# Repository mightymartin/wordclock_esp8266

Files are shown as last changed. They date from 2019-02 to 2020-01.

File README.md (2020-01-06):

# Wordclock based on an ESP8266 / WS2812
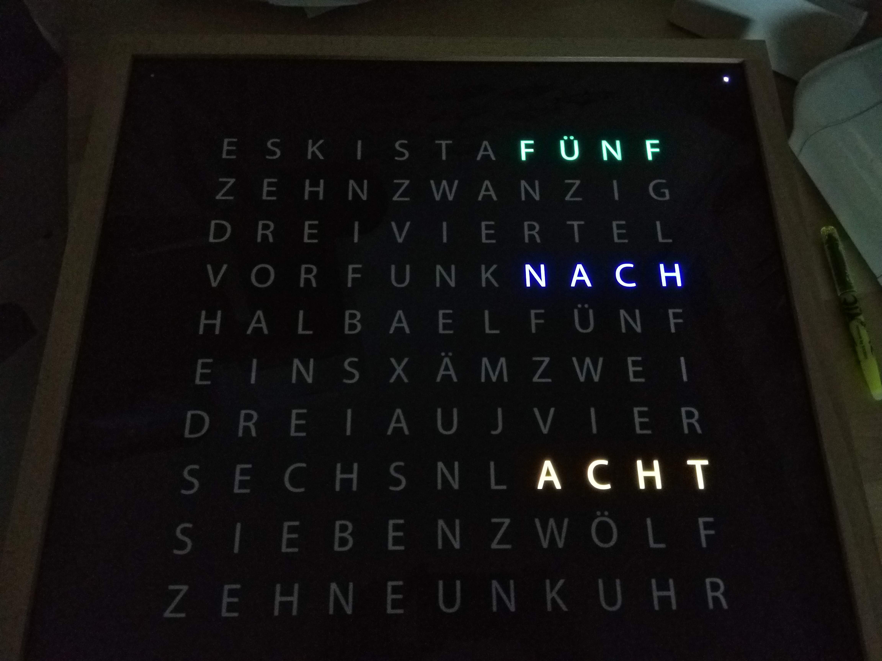
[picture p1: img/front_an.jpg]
front_an


## Hardware:
- LDR with voltagedevider on A0 
- WS2812 via levelshifter on RXD0 

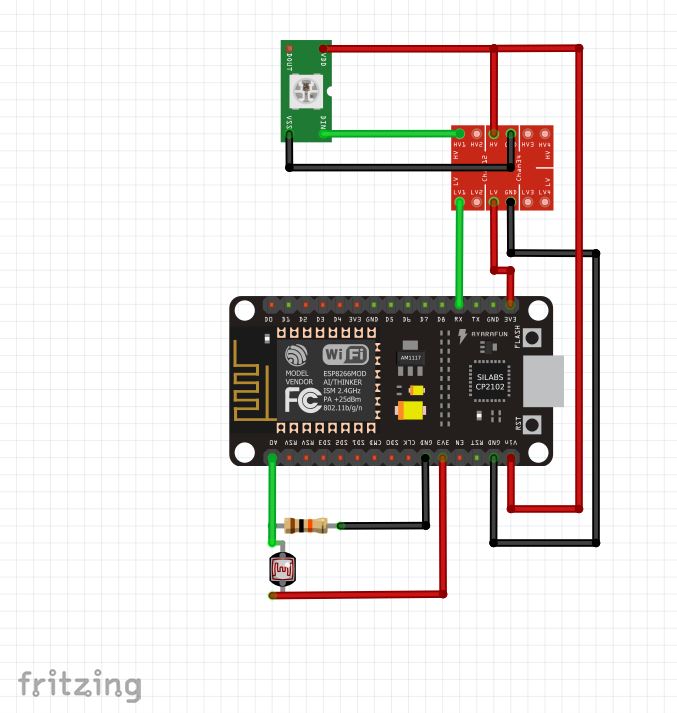
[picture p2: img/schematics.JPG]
wiring1


## Supported Layouts:
#Ikeahacker caschoff.de (page gone):
```
E S _ I S T _ F Ü N F
Z E H N Z W A N Z I G
D R E I V I E R T E L
N A C H F U N K V O R  
H A L B _ E L F Ü N F
E I N S _ _ _ Z W E I
D R E I _ _ _ V I E R
S E C H S _ _ A C H T
S I E B E N Z W Ö L F
Z E H N N E U N U H R
```

#ulrichradig.de (project gone):
```
E S _ I S T _ F Ü N F
Z E H N Z W A N Z I G
D R E I V I E R T E L
_ _ N A C H V O R _ _  
H A L B _ Z W Ö L F _
Z W E I N S I E B E N
_ D R E I _ _ F Ü N F
E L F N E U N V I E R
_ A C H T Z E H N _ _
_ S E C H S _ U H R _
```

#mikrocontroller.net:
```
E S _ I S T _ F Ü N F
Z E H N Z W A N Z I G
D R E I V I E R T E L
_ _ N A C H V O R _ _  
H A L B _ Z W Ö L F _
Z W E I N S I E B E N
_ D R E I _ _ F Ü N F
E L F N E U N V I E R
_ A C H T Z E H N _ _
_ S E C H S _ _ U H R
```

## Features:
- defineable hardware layout (leds.h)
- word fading
- display hour and minutes
- display seconds
- display temperature
- display marquee text
- display startscreen
- scheduled Auto ON / OFF Times
- 8 different color modes with HUE rotate
- wifimanger
- Webserver http://deviceip:80 ( inspired by Tasmota and tzapu/wifimanager )
- OTA
- mdns
- Websocket Webconsole
- NTP time client
- MQTT Sub: ON/OFF && BRIGHTNESS && COLORMODE && DISPLAYMODE (Non persistent)
- MQTT Pub: current config as JSON to broker
- LDR driven brightness

## Images
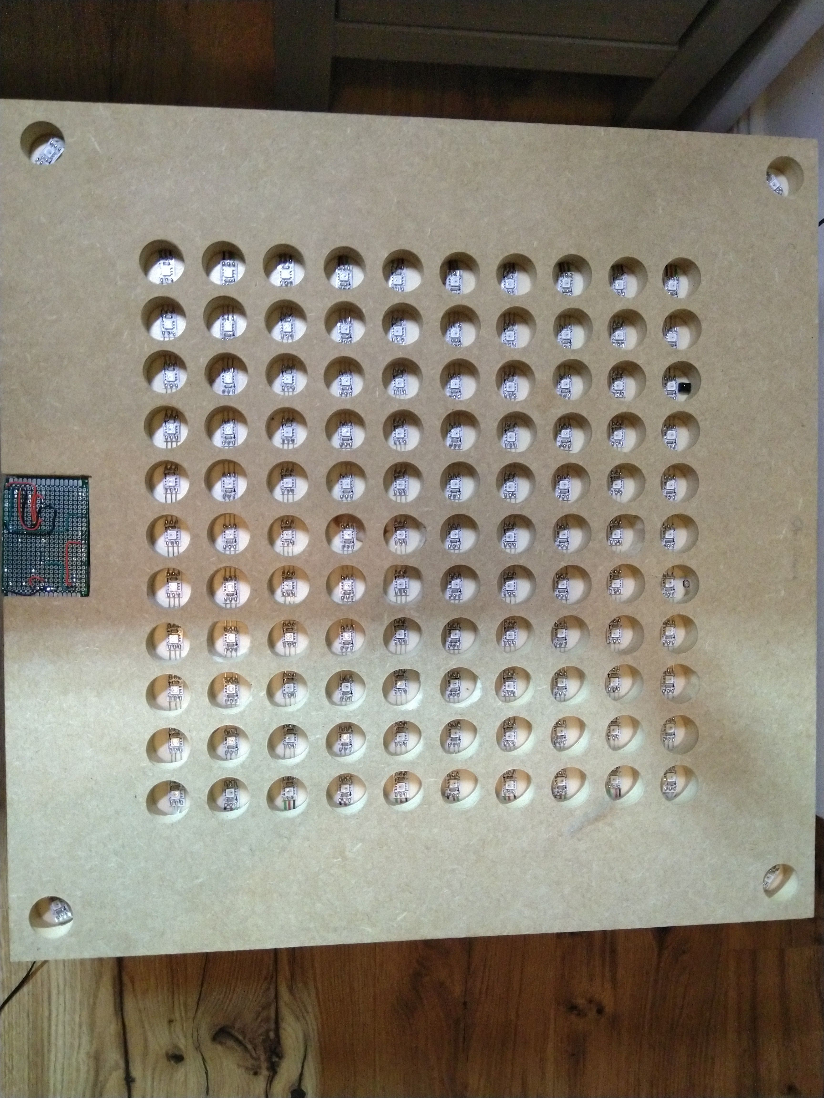
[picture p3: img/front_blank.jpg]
front_blank

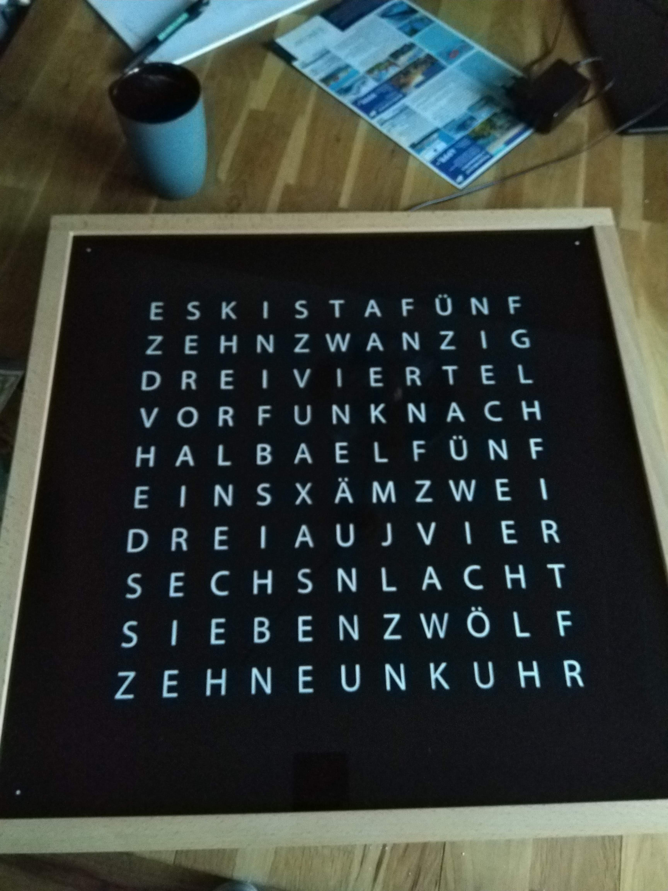
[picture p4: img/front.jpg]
front

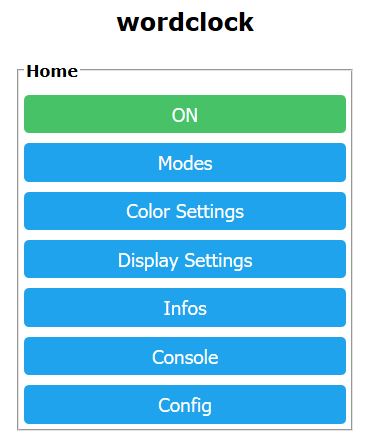
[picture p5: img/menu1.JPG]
menu1

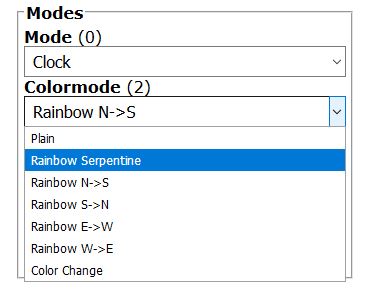
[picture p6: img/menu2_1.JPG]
menu21

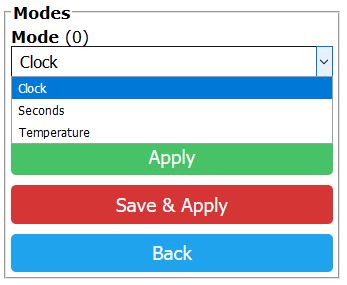
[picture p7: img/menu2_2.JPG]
menu22

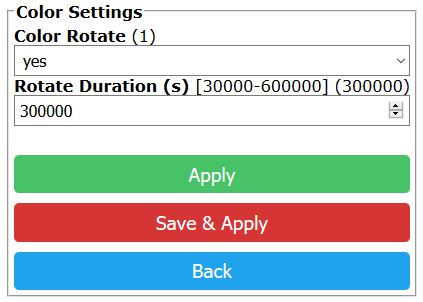
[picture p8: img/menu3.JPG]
menu3

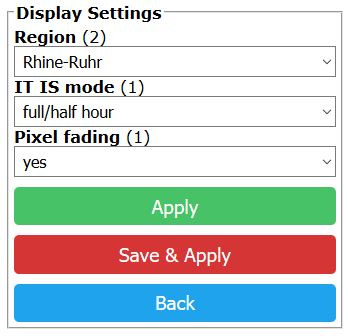
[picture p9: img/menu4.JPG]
menu4

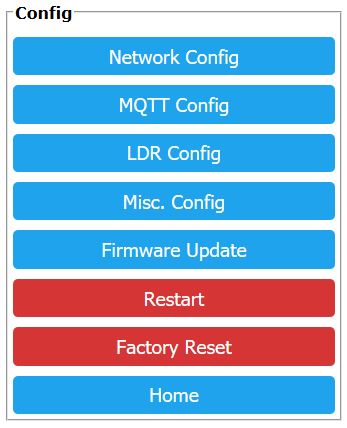
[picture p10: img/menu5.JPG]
menu5

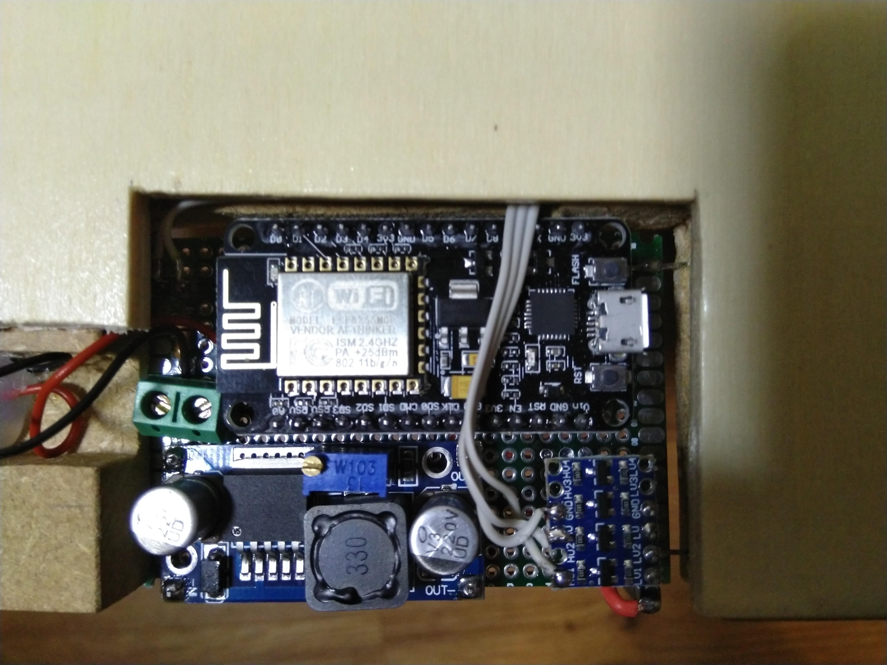
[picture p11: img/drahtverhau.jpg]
wiring2


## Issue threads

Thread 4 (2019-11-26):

Feature Request: define on/off times

ojaatka, 2019-11-26:
Hi,

hope it is allowed to ask for features here.

It would be nice if the wordclock can be switched ob by night
e.G from 00:00 to 06:00 in my case

mightymartin, 2019-11-27:
Hi,

of course it is! I was planning to implement some new features on christmas holiday, so chances will be good.

i am thinking of some classic "notch in"-timer design, so you can check the on-time-hours of the day. (eg 000000001111111111110000 is 8am to 8pm)

regards
Martin

ojaatka, 2019-11-27:
Great, thanks for that.
I'm using HomeAssistant meanwhile I'm going to look at the MQTT interface.
Possibly I can also use an automation to do this.

mightymartin, 2020-01-06:
Hi,

there is an auto on/off feature now. it switches the clock on or off to the given times, so you are able to do it manually in the mean time.

ojaatka, 2020-01-09:
Thanks!

Closed 2020-01-06.

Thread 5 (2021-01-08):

Wordcklock von Ulrich Radig lebt

dbambus, 2021-01-08:
Hallo @mightymartin,

ich bin grade auf dein Projekt hier auf Github gestoßen und habe deine Übersicht der Wordclock Varianten gesehen. Hier wollte ich nur ergänzen, dass ich den Code von Ulrich Radig aktiv weiterentwickle :-).

Wird doch mal einen Blick auf https://github.com/dbambus/Worduhr :-)

mightymartin, 2021-01-08:
Hi,Danke für den Hinweis. Bei der Radig Variante hab ich nur aufgenommen, damit ich die als alternative zu der Spaghetti-Code Software in Forum stellen konnte. Die Neuimplementierung hat mich weniger zeit gekostet als das Anpassen ;) Zumal die Entwicklung Stile auch auseinander laufen :)VGMartinAm 08.01.2021 09:42 schrieb dbambus <notifications@github.com>:

Hallo @mightymartin,

ich bin grade auf dein Projekt hier auf Github gestoßen und habe deine Übersicht der Wordclock Varianten gesehen. Hier wollte ich nur ergänzen, dass ich den Code von Ulrig Radig aktiv weiterentwickle :-).

Wird doch mal einen Blick auf https://github.com/dbambus/Worduhr :-)

—You are receiving this because you were mentioned.Reply to this email directly, view it on GitHub, or unsubscribe.

Closed 2021-01-08.

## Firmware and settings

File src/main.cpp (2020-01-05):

#include <ESP8266WebServer.h>
#include <ESP8266HTTPUpdateServer.h>
#include <ESP8266mDNS.h>
#include <WiFiManager.h>

#include "logging.h"
#include "leds.h"
#include "color.h"
#include "timeNTP.h"
#include "draw.h"
#include "ldr.h"
#include "settings.h"
#include "website.h"
#include "mqtt.h"


//##############################
//## Instances
//##############################
ESP8266WebServer server(CONF_WEBSERVER_PORT);
ESP8266HTTPUpdateServer httpUpdaterServer;

//##############################
//## Setup
//##############################

void setup() {
  //### calm after reset
  delay(250);
  
  //### Starte Serial  
  WebLogInit();
  Serial.begin(CONF_SERIAL_BAUD);

  WebLogInfo("");
  WebLogInfo("--- Init ---");
  
  WebLogInfo("Init Settings");
  SettingsInit();

  WebLogInfo("Start Hardware init");
  LedInit();  
  ColorInit();
  DrawInit();
  LDRInit();

  wifi_station_set_hostname(settings.n_hostname);
  WiFi.hostname(settings.n_hostname);

  WebLogInfo("Start Wifimanger");
  WiFiManager wifiManager;  
  wifiManager.setConnectTimeout(10);
  wifiManager.setConfigPortalTimeout(180);
  //wifiManager.setSaveConfigCallback(saveConfigCallback);
  if(settings.u_LOGGING >= LOGLEVEL_DBG){
    wifiManager.setDebugOutput(true);
  }  
  wifiManager.autoConnect(settings.n_hostname, NULL);

  //NTP Zeit
  WebLogInfo("Start Time init");
  TimeInit();

  //### Init Website
  WebLogInfo("Init Website");
  WebsiteInit(&server);  
  
  //### Init UpdateServer 
  WebLogInfo("Init Updateserver");
  httpUpdaterServer.setup(&server,REQ_OTA);
  
  //### Start Webserver
  WebLogInfo("Start Webserver");
  server.begin();

  if(settings.u_MQTT){
    //### Start MQTT
    WebLogInfo("Start MQTT");
    MQTTInit();
  }

  //### Start mDNS
  if(settings.u_MDNS == 1){
      WebLogInfo("Start mDNS");
      MDNS.begin(settings.n_hostname); 
      MDNS.addService("http", "tcp", CONF_WEBSERVER_PORT);      
      MDNS.addService("ws", "tcp", CONF_WEBSOCKET_PORT); 
      if(settings.u_MQTT){
          MDNS.addService("mqtt", "tcp", settings.m_port);
      }
  }

  WebLogInfo("--- Init End ---");
}

//##############################
//## Main Loop
//##############################

void loop() {  
  ColorTick();
  LedTick();
  DrawTick();
  TimeTick();  
  
  if(settings.u_LDR){
    LDRTick();
  }
  
  WebLogTick();
  
  if(settings.u_MQTT){
    MQTTTick(); 
  }

  SettingsTick();

  server.handleClient();  

  if(settings.u_MDNS == 1){
    MDNS.update();
  }
}

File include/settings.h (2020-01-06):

#ifndef SETTINGS_H
#define SETTINGS_H

#include <ESP8266WiFi.h> 
#include <Arduino.h> 
#include <EEPROM.h>
#include <Ticker.h>

#define QUOTE(...) #__VA_ARGS__

#define EEPROM_START_ADDRESS    0
#define EEPROM_SIZE             4095

#define FW_VERSION              "0.13"
#define CONF_WEBSERVER_PORT     80
#define CONF_WEBSOCKET_PORT     81
#define CONF_SERIAL_BAUD        115200
#define MAX_FADE_STEPS	        32

#if (MAX_FADE_STEPS==32)
    const uint8 pwm_table[MAX_FADE_STEPS] = {
                                                        0,   1,   3,   4,   5,   6,   7,   8,
                                                        9,  10,  12,  14,  16,  18,  21,  24,
                                                        28,  32,  37,  42,  48,  55,  63,  72,
                                                        83,  96, 111, 129, 153, 182, 216, 255
                                                    };
#else
    #error unknown pwm step size
#endif


#define G_VERSION                   "GVER"   
#define G_TIME                      "GTIME"   

#define U_LDR_TAG                   "ULDR"   
#define U_MQTT_TAG                  "UMQTT" 
#define U_MDNS_TAG                  "UMDNS" 
#define U_LOGG_TAG                  "ULOGG" 
#define U_ONOFF_TAG                 "UONOFF" 
#define U_AUTOON_TAG                "UAON" 
#define U_AUTOOFF_TAG               "UAOFF" 

#define N_NTPINTERVAL_TAG           "NNTPI" 
#define N_NTPSERVER_TAG             "NNTPS"
#define N_HOSTNAME_TAG              "NHOST"
#define M_PORT_TAG                  "MPORT"
#define M_HOST_TAG                  "MBROK"
#define M_CLIENT_ID_TAG             "MCLID"
#define M_USER_TAG                  "MUSER"
#define M_PASS_TAG                  "MPASS" 
#define M_TOPIC_TAG                 "MTOP"
#define C_MODE_TAG                  "CMODE"
#define C_HUE_ROTATE_RB_TAG         "CROT"
#define C_HUE_ROTATE_DURATION_TAG   "CROTD"
#define C_PLAIN_RED_TAG             "CRED"
#define C_PLAIN_GREEN_TAG           "CGREE"
#define C_PLAIN_BLUE_TAG            "CBLUE"
#define C_BRIGHTNESS_TAG            "CBRIG"

#define L_MIN_BRIGHT_TAG            "LDMI"
#define L_TRESHOLD_TAG              "LDTR"

#define D_MODE_TAG                  "DMODE"
#define D_CLK_REGION_TAG            "DREGI"
#define D_CLK_ITIS_MODE_TAG         "DITIS"
#define D_CLK_FADE_TAG              "DFADE" 

#define D_TEMP_TAG                  "DTEMP"
#define D_TEXT_TIMEOUT_TAG          "DTETI"
#define D_TEXT_TAG                  "DTEXT"
#define D_TEXT_SPEED_TAG            "DTESP" 


struct Settings_t{
    //General
    char      version[5]              ; 
    uint8     u_LDR                   ;
    uint8     u_MQTT                  ;
    uint8     u_MDNS                  ;
    uint8     u_LOGGING               ;
    uint8     u_DISPLAYON             ;
    uint8     u_AUTO_ON               ;
    uint8     u_AUTO_OFF              ;

    //network
    uint32_t    n_ntpinterval           ;
    char        n_ntpserver[32]         ;    
    char        n_hostname[32]          ;

    //MQTT
    uint16_t    m_port                  ;
    char        m_host[32]              ;    
    char        m_client_id[32]         ;
    char        m_user[32]              ;
    char        m_pass[32]              ;
    char        m_topic[32]             ;

    //Color
    uint8       c_mode                  ;
    uint8       c_hue_rotate_rb         ;
    uint32_t    c_hue_rotate_duration   ;
    uint8       c_plain_red             ;
    uint8       c_plain_green           ;
    uint8       c_plain_blue            ;
    
    uint8       c_brightness            ;
    
    uint8       l_min_bright            ;    
    uint16      l_treshold[10]          ;
    
    //Draw
    uint8       d_mode                  ;
    uint8       d_clk_region            ;
    uint8       d_clk_itis_mode         ;
    uint8       d_clk_fade              ;
    int8        d_temperatur            ;
    char        d_text[256]             ;

    uint8       d_text_timeout          ;
    uint8       d_text_speed            ;
    
    
}  __attribute__((packed));

extern Settings_t settings;

extern uint8    doRestart;

extern void     SettingsInit();

extern void     SettingsSetDefaults();

extern uint32_t SettingsGetChecksum();
extern void     SettingsSetValue(String key, String value);
extern String   SettingsToJson();

extern void     SettingsWrite();
extern void     SettingsRead();
extern void     SettingsClear();

extern void     SettingsTick();
extern void     SettingsUpdate();

extern void     SettingsWifiReset();
extern void     SettingsSoftRestart();
extern void     SettingsTick();

#endif

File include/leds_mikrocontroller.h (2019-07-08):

#ifndef LEDS_MIKROCONTROLLER_H_
#define LEDS_MIKROCONTROLLER_H_

#include "leds.h"

//###############
//## THX to WStruhalla @ github
//##
//## ES_IST_FÜNF
//## ZEHNZWANZIG
//## DREIVIERTEL
//## __NACHVOR__  
//## HALB_ZWÖLF_
//## ZWEINSIEBEN
//## _DREI__FÜNF
//## ELFNEUNVIER
//## _ACHTZEHN__
//## _SECHS__UHR
//###############

#define LED_MATRIX_ROWS 10
#define LED_MATRIX_COLS 11
#define LED_DOTS 4
#define LED_COUNT (LED_MATRIX_ROWS * LED_MATRIX_COLS) + LED_DOTS

const uint8 matrixIndex[LED_MATRIX_ROWS][LED_MATRIX_COLS] =         {                              
                                                                        {109,108,107,106,105,104,103,102,101,100, 99},
                                                                        { 88, 89, 90, 91, 92, 93, 94, 95, 96, 97, 98},
                                                                        { 87, 86, 85, 84, 83, 82, 81, 80, 79, 78, 77},
                                                                        { 66, 67, 68, 69, 70, 71, 72, 73, 74, 75, 76},
                                                                        { 65, 64, 63, 62, 61, 60, 59, 58, 57, 56, 55},
                                                                        { 44, 45, 46, 47, 48, 49, 50, 51, 52, 53, 54},
                                                                        { 43, 42, 41, 40, 39, 38, 37, 36, 35, 34, 33},
                                                                        { 22, 23, 24, 25, 26, 27, 28, 29, 30, 31, 32},
                                                                        { 21, 20, 19, 18, 17, 16, 15, 14, 13, 12, 11},
                                                                        {  0,  1,  2,  3,  4,  5,  6,  7,  8,  9, 10}
                                                                    };

const uint8 dotsIndex[LED_DOTS] =           {
                                                110, 111, 112, 113
                                            };

//##############################
//## Define Methods
//##############################

//#### Fill Words
static inline void LedSetEsIst(uint8 hard){    
    uint8 mode = hard ? LED_STATIS_ON : LED_STATIS_FADEIN;
    //Es
    LedSetStatusMatrix(0,0,mode);
    LedSetStatusMatrix(0,1,mode);

    //Ist
    LedSetStatusMatrix(0,3,mode);
    LedSetStatusMatrix(0,4,mode);
    LedSetStatusMatrix(0,5,mode);
}

static inline void LedSetUhr(uint8 hard){    
    uint8 mode = hard ? LED_STATIS_ON : LED_STATIS_FADEIN;
    LedSetStatusMatrix(9,8,mode);
    LedSetStatusMatrix(9,9,mode);
    LedSetStatusMatrix(9,10,mode);
}

static inline void LedSetVor(uint8 hard){    
    uint8 mode = hard ? LED_STATIS_ON : LED_STATIS_FADEIN;
    LedSetStatusMatrix(3,0,mode);
    LedSetStatusMatrix(3,1,mode);
    LedSetStatusMatrix(3,2,mode);
}

static inline void LedSetNach(uint8 hard){    
    uint8 mode = hard ? LED_STATIS_ON : LED_STATIS_FADEIN;
    LedSetStatusMatrix(3,7,mode);
    LedSetStatusMatrix(3,8,mode);
    LedSetStatusMatrix(3,9,mode);
    LedSetStatusMatrix(3,10,mode);
}

static inline void LedSetFunk(uint8 hard){    
    uint8 mode = hard ? LED_STATIS_ON : LED_STATIS_FADEIN;
    LedSetStatusMatrix(3,3,mode);
    LedSetStatusMatrix(3,4,mode);
    LedSetStatusMatrix(3,5,mode);
    LedSetStatusMatrix(3,6,mode);
}

//#### Minutes Words
static inline void LedSetFuenfMin(uint8 hard){    
    uint8 mode = hard ? LED_STATIS_ON : LED_STATIS_FADEIN;
    LedSetStatusMatrix(0,7,mode);
    LedSetStatusMatrix(0,8,mode);
    LedSetStatusMatrix(0,9,mode);
    LedSetStatusMatrix(0,10,mode);
}

static inline void LedSetZehnMin(uint8 hard){    
    uint8 mode = hard ? LED_STATIS_ON : LED_STATIS_FADEIN;
    LedSetStatusMatrix(1,0,mode);
    LedSetStatusMatrix(1,1,mode);
    LedSetStatusMatrix(1,2,mode);
    LedSetStatusMatrix(1,3,mode);
}

static inline void LedSetZwanzigMin(uint8 hard){    
    uint8 mode = hard ? LED_STATIS_ON : LED_STATIS_FADEIN;
    LedSetStatusMatrix(1,4,mode);
    LedSetStatusMatrix(1,5,mode);
    LedSetStatusMatrix(1,6,mode);
    LedSetStatusMatrix(1,7,mode);
    LedSetStatusMatrix(1,8,mode);
    LedSetStatusMatrix(1,9,mode);
    LedSetStatusMatrix(1,10,mode);
}

static inline void LedSetViertelMin(uint8 hard){    
    uint8 mode = hard ? LED_STATIS_ON : LED_STATIS_FADEIN;    
    LedSetStatusMatrix(2,4,mode);
    LedSetStatusMatrix(2,5,mode);
    LedSetStatusMatrix(2,6,mode);
    LedSetStatusMatrix(2,7,mode);
    LedSetStatusMatrix(2,8,mode);
    LedSetStatusMatrix(2,9,mode);
    LedSetStatusMatrix(2,10,mode);
}

static inline void LedSetDreiviertelMin(uint8 hard){    
    uint8 mode = hard ? LED_STATIS_ON : LED_STATIS_FADEIN;
    LedSetStatusMatrix(2,0,mode);
    LedSetStatusMatrix(2,1,mode);
    LedSetStatusMatrix(2,2,mode);
    LedSetStatusMatrix(2,3,mode);
    LedSetViertelMin(hard);
}

static inline void LedSetHalbMin(uint8 hard){    
    uint8 mode = hard ? LED_STATIS_ON : LED_STATIS_FADEIN;    
    LedSetStatusMatrix(4,0,mode);
    LedSetStatusMatrix(4,1,mode);
    LedSetStatusMatrix(4,2,mode);
    LedSetStatusMatrix(4,3,mode);    
}

static inline void LedSetMinDot(uint8 dot, uint8 hard){    
    uint8 mode = hard ? LED_STATIS_ON : LED_STATIS_FADEIN;    
    LedSetStatusMinute(dot,mode);    
}

//#### Hours Words
static inline void LedSetEinHour(uint8 hard){    
    uint8 mode = hard ? LED_STATIS_ON : LED_STATIS_FADEIN;    
    LedSetStatusMatrix(5,0,mode);
    LedSetStatusMatrix(5,1,mode);
    LedSetStatusMatrix(5,2,mode);      
}

static inline void LedSetEinsHour(uint8 hard){    
    uint8 mode = hard ? LED_STATIS_ON : LED_STATIS_FADEIN;    
    LedSetEinHour(mode);
    //s
    LedSetStatusMatrix(5,3,mode);    
}

static inline void LedSetZweiHour(uint8 hard){    
    uint8 mode = hard ? LED_STATIS_ON : LED_STATIS_FADEIN;    
    LedSetStatusMatrix(5,7,mode);
    LedSetStatusMatrix(5,8,mode);
    LedSetStatusMatrix(5,9,mode);      
    LedSetStatusMatrix(5,10,mode);
}

static inline void LedSetDreiHour(uint8 hard){    
    uint8 mode = hard ? LED_STATIS_ON : LED_STATIS_FADEIN;    
    LedSetStatusMatrix(6,0,mode);
    LedSetStatusMatrix(6,1,mode);
    LedSetStatusMatrix(6,2,mode);      
    LedSetStatusMatrix(6,3,mode);      
}

static inline void LedSetVierHour(uint8 hard){    
    uint8 mode = hard ? LED_STATIS_ON : LED_STATIS_FADEIN;    
    LedSetStatusMatrix(6,7,mode);
    LedSetStatusMatrix(6,8,mode);
    LedSetStatusMatrix(6,9,mode);      
    LedSetStatusMatrix(6,10,mode);  
}

static inline void LedSetFuenfHour(uint8 hard){    
    uint8 mode = hard ? LED_STATIS_ON : LED_STATIS_FADEIN;    
    LedSetStatusMatrix(4,7,mode);
    LedSetStatusMatrix(4,8,mode);
    LedSetStatusMatrix(4,9,mode);      
    LedSetStatusMatrix(4,10,mode);  
}
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

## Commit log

2019-02-11 Fiexe Bug: - Color HUE value at color rotate flips on overflow
    [draw.cpp, main.cpp]
2019-02-23 several fixes and features
    [draw.cpp, draw.h, main.cpp]
2019-02-23 weblog console / ldr fix
    [draw.cpp, main.cpp, settings.h]
2019-02-27 schematic / readme
    [sketch.fzz]
2019-03-20 Fixed Hostname mDNS / DHCP
    [main.cpp]
2019-07-08 added two additional layout (mikrocontroller.net/ulrichradig.de) with their traditional wiring
2020-01-05 draft1 display text and temperature set via mqtt
2020-01-05 - temp range -9 to 99 C - text shorter than 3 chars is okay now
    [draw.cpp, draw.h, settings.h]
